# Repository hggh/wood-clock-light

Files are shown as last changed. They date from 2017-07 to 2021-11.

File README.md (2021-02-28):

# wood clock with ESP32

a rainbow wood clock with a custom LED matrix with 95 PL9823-F8 RBG LEDs.

 * ESP32
 * 85x pl9823-f8

### rainbow mode
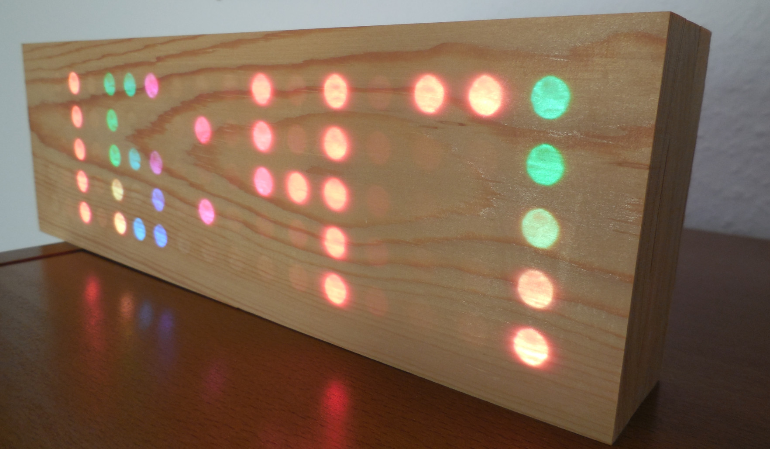
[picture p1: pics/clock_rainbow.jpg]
Wood Clock Wood rainbow

### single color mode controllable via web
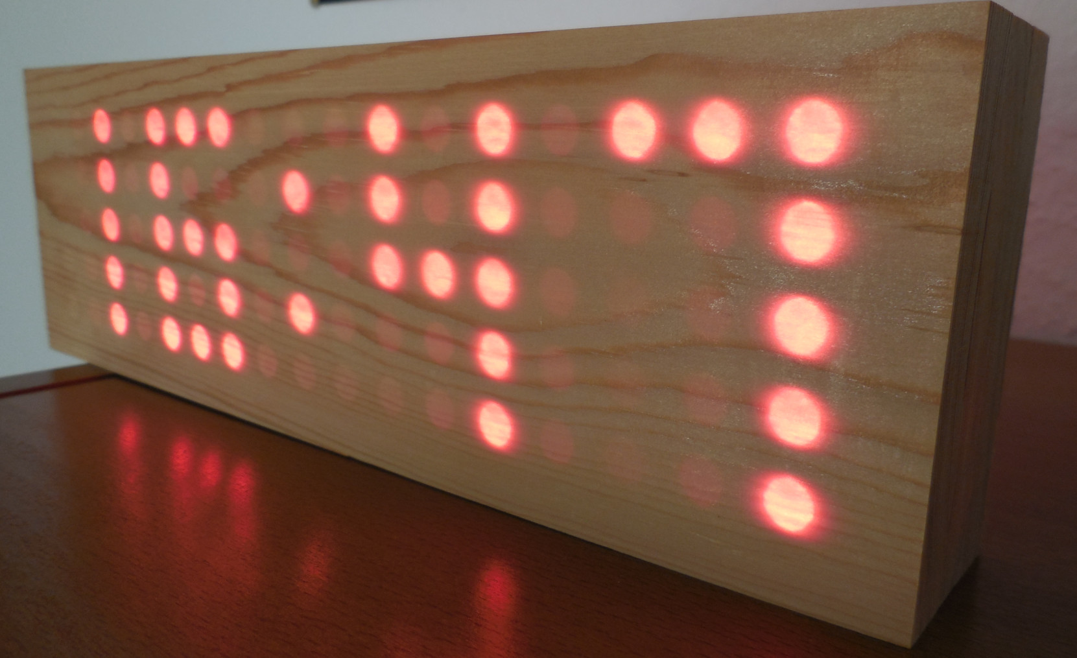
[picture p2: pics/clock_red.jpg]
Wood Clock Wood red

### simple web interface
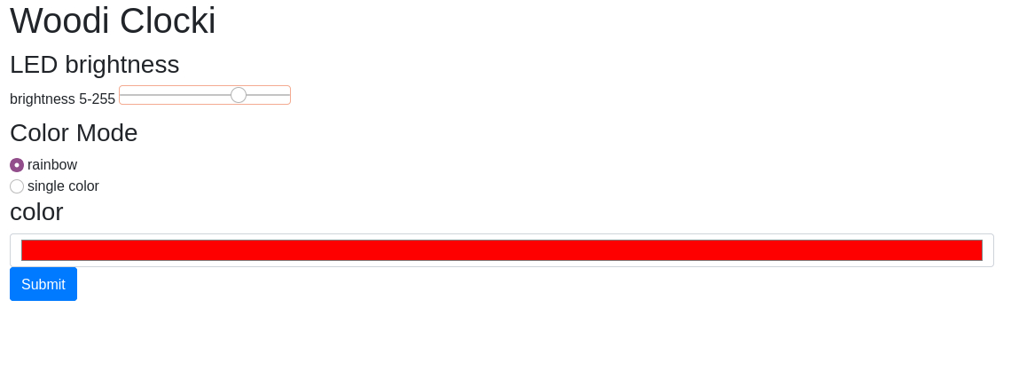
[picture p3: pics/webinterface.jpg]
Wood Clock web interface

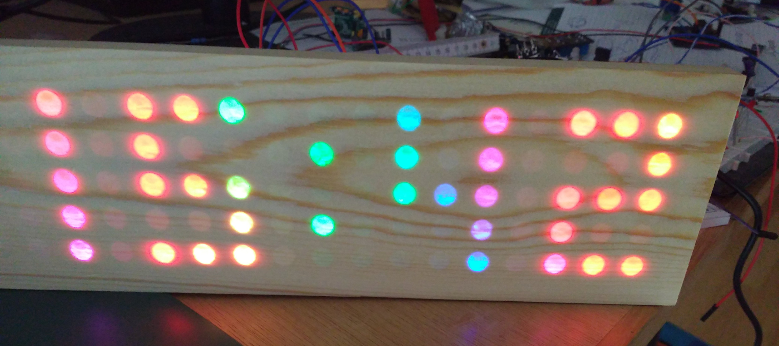
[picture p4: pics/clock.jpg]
Wood Clock


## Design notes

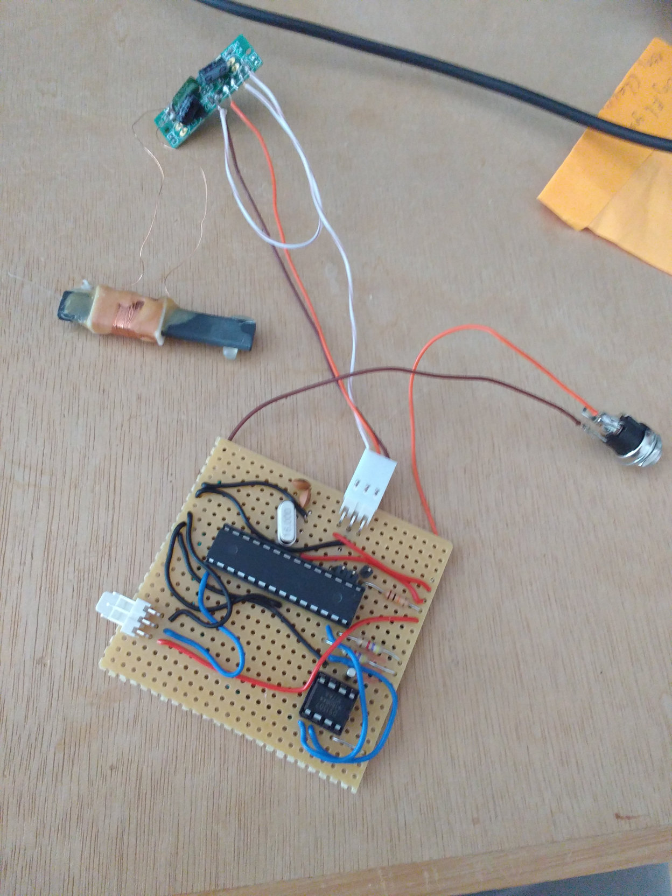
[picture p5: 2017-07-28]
pics/pcb.jpg

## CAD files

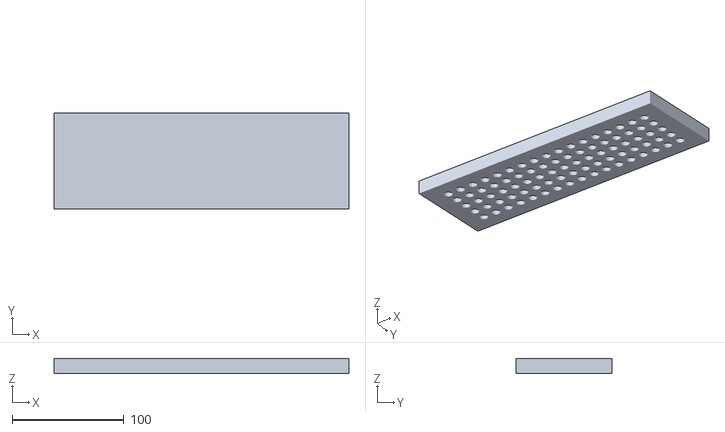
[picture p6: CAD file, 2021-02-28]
svg/wood-clock.stl
264.0 x 86.0 x 13.0

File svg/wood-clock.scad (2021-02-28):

difference() {
  cube(size = [264,86,13]);
  for (e = [ 0 : 4 ]) {
    for (i = [0 : 16]) {
      translate([(20 + (i * 14)),17 + (e *13),0]) {
        cylinder (h = 12.2, r=4, center=false);
      }
    }
  }
}

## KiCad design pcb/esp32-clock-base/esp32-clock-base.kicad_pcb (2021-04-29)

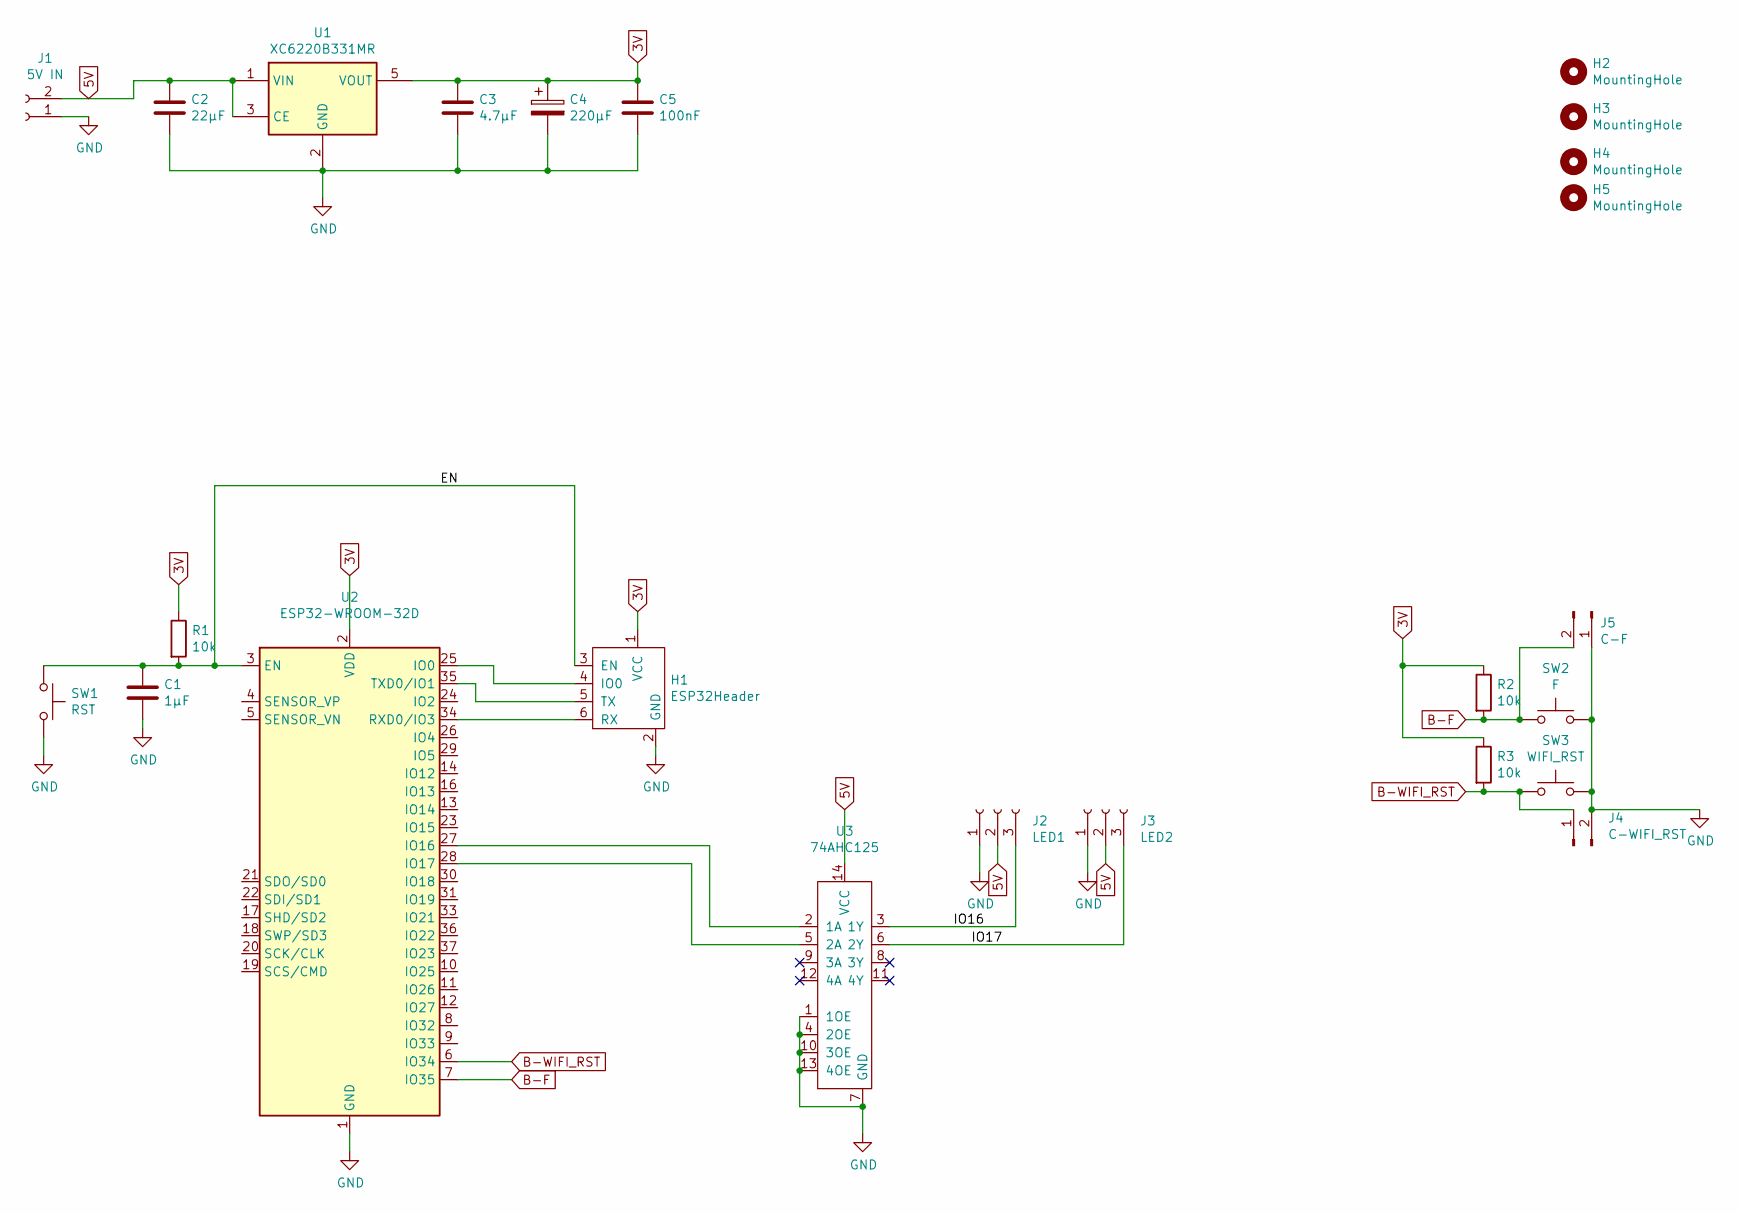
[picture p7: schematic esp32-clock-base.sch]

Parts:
C1: 1µF; C_0805_2012Metric
C2: 22µF; C_0805_2012Metric
C3: 4.7µF; C_0805_2012Metric
C4: 220µF; CP_EIA-7343-31_Kemet-D
C5: 100nF; C_0805_2012Metric
H1: ESP32Header; esp32-prog-header
H2, H3, H4, H5: MountingHole; MountingHole_3.2mm_M3
J1: 5V IN; PinHeader_1x02_P2.54mm_Vertical
J2: LED1; PinHeader_1x03_P2.54mm_Horizontal
J3: LED2; PinHeader_1x03_P2.54mm_Horizontal
J4: C-WIFI_RST; PinHeader_1x02_P2.00mm_Vertical
J5: C-F; PinHeader_1x02_P2.00mm_Vertical
R1, R2, R3: 10k; R_0805_2012Metric
SW1: RST; SMD_Button
SW2: F; SMD_Button
SW3: WIFI_RST; SMD_Button
U1: XC6220B331MR; SOT-23-5
U2: ESP32-WROOM-32D; ESP32-WROOM-32
U3: 74AHC125; SO-14_3.9x8.65mm_P1.27mm

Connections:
3V: C3.1, C4.1, C5.1, H1.1 (VCC), R1.1, R2.1, R3.1, U1.5 (VOUT), U2.2 (VDD)
5V: C2.1, J1.2, J2.2, J3.2, U1.1 (VIN), U1.3 (CE), U3.14 (VCC)
/EN: C1.1, H1.3 (EN), R1.2, SW1.1, U2.3 (EN)
/IO16: J2.3, U3.3 (1Y)
/IO17: J3.3, U3.6 (2Y)
B-F: J5.2, R2.2, SW2.1, U2.7 (IO35)
B-WIFI_RST: J4.1, R3.2, SW3.1, U2.6 (IO34)
GND: C1.2, C2.2, C3.2, C4.2, C5.2, H1.2 (GND), J1.1, J2.1, J3.1, J4.2, J5.1, SW1.2, SW2.2, SW3.2, U1.2 (GND), U2.1 (GND), U2.15 (GND), U2.38 (GND), U2.39 (GND), U3.1 (1OE), U3.4 (2OE), U3.7 (GND), U3.10 (3OE), U3.13 (4OE)
unnamed: H1.4 (IO0), U2.25 (IO0)
unnamed: H1.5 (TX), U2.35 (TXD0/IO1)
unnamed: H1.6 (RX), U2.34 (RXD0/IO3)
unnamed: U2.27 (IO16), U3.2 (1A)
unnamed: U2.28 (IO17), U3.5 (2A)

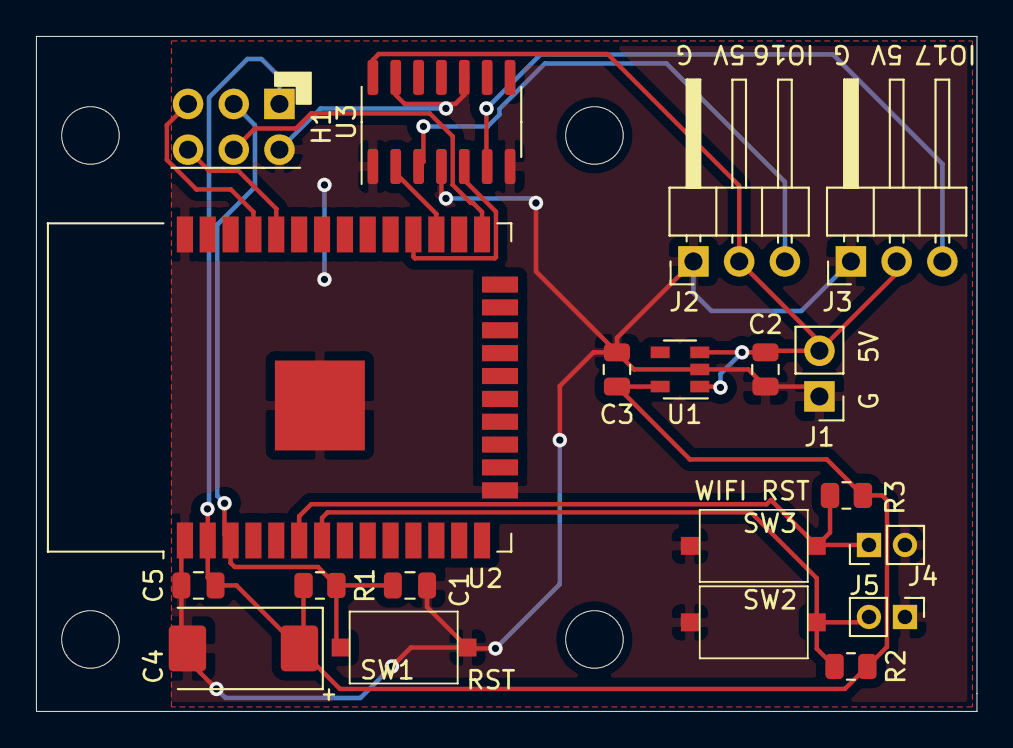
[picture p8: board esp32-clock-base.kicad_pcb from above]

Board: 2 copper layers, 52.2 x 37.5 mm, 24 parts (0 on the bottom side), 13 nets.

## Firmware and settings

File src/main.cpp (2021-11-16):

#include <Arduino.h>
#include "SPIFFS.h"
#include <WiFi.h>
#include <WiFiClient.h>
#include <WiFiClientSecure.h>
#include <time.h>

#include <FastLED.h>
#include <Bounce2.h>
#include <FS.h>
#include <WiFiManager.h>
#include <WebServer.h>
#include <MQTT.h>

#include "display.h"
#include "config.h"

// we have one sacrificial LED with a diode on VCC to push VDD
#define LED_COUNT 85
#define PIN_RGB_LEDS 17
#define PIN_WIFI_RESET 34

#define COLOR_MODE_RAINBOW 1
#define COLOR_MODE_SINGLE_COLOR 2

CRGB leds[LED_COUNT];
CRGB led_color = CRGB::Red;
WiFiManager wm;
WiFiClientSecure net;
MQTTClient mqtt;
Bounce2::Button wifi_cfg_reset = Bounce2::Button();

const long gmt_offset_sec = 3600;
const int  day_light_offset_sec = 3600;

uint8_t time_hour = 255;
uint8_t time_minute = 255;
uint8_t color_mode = COLOR_MODE_RAINBOW;
int led_brightness = 60;
volatile bool auth_token = false;
uint8_t auth_token_number = 0;
bool update_leds = false;
CHSV hsv;

void write_char_to_leds(uint8_t offset, const uint8_t n[15]) {
  for (uint8_t i = 0; i<15; i++) {
    if (n[i] == 1) {
      if (color_mode == COLOR_MODE_RAINBOW) {
        leds[offset + i] = hsv;
        hsv.hue += 10;
      }
      else {
        leds[offset + i] = led_color;
      }
    }
    else {
      leds[offset + i] = CRGB::Black;
    }
  }
}

void clock_display_number(uint8_t offset, uint8_t number, boolean display_zero = false) {
  uint8_t t_first = ((number / 10 ) % 10);
  uint8_t t_second = (number % 10 );

  if (display_zero == true || t_first != 0 ) {
    write_char_to_leds(offset, numbers[t_first]);
  }
  write_char_to_leds(offset + 20, numbers[t_second]);
}

void mqtt_message_received(MQTTClient *client, char topic[], char bytes[], int length) {
  if (String(topic).endsWith("/led_brightness")) {
    update_leds = true;
    led_brightness = String(bytes).toInt();
    FastLED.setBrightness(led_brightness);
  }
  if (String(topic).endsWith("/auth_token")) {
    auth_token = true;
    auth_token_number = String(bytes).toInt();
  }
  if (String(topic).endsWith("/led_color")) {
    update_leds = true;

    String color_string = String(bytes);
    color_string.replace("#", "");
    long color_code_tmp = strtol(color_string.c_str(), NULL, 16);
    led_color = CRGB(color_code_tmp);
  }
  if (String(topic).endsWith("/color_mode")) {
    update_leds = true;

    if (String(bytes).equals("random_color")) {
      color_mode = COLOR_MODE_RAINBOW;
    }
    else {
      color_mode = COLOR_MODE_SINGLE_COLOR;
    }
  }
}

void connect_mqtt() {
  mqtt.connect(HOSTNAME, MQTT_USERNAME, MQTT_PASSWORD);
  mqtt.subscribe(String("/device/" + String(HOSTNAME) + "/led_brightness").c_str(), 1);
  mqtt.subscribe(String("/device/" + String(HOSTNAME) + "/auth_token").c_str(), 1);
  mqtt.subscribe(String("/device/" + String(HOSTNAME) + "/color_mode").c_str(), 1);
  mqtt.subscribe(String("/device/" + String(HOSTNAME) + "/led_color").c_str(), 1);
  mqtt.subscribe(String("/device/" + String(HOSTNAME) + "/show_minute_leds").c_str(), 1);
  mqtt.onMessageAdvanced(mqtt_message_received);
  mqtt.publish(String("/device/" + String(HOSTNAME) + "/boot").c_str(), WiFi.localIP().toString().c_str(), false, 1);
}

void wm_config_mode_callback(WiFiManager *myWiFiManager) {
  Serial.println("Entering WiFI Manager configuration....");

  fill_solid(leds, LED_COUNT, CRGB::DeepPink);
  FastLED.setBrightness(10);
  FastLED.show();
}

void setup() {
  Serial.begin(115200);
  btStop();
  WiFi.mode(WIFI_STA);
  WiFi.setHostname(HOSTNAME);
  Serial.begin(115200);

  hsv.hue = 1;
  hsv.val = 255;
  hsv.sat = 240;

  FastLED.addLeds<PL9823, PIN_RGB_LEDS>(leds, LED_COUNT);
  FastLED.setBrightness(led_brightness);

  if(!SPIFFS.begin(true)){
    Serial.println("error on SPIFFS...");
  }
  wm.setAPCallback(wm_config_mode_callback);
  wm.autoConnect(HOSTNAME, "");

  FastLED.clear(true);

  configTime(gmt_offset_sec, day_light_offset_sec, "0.de.pool.ntp.org", "1.de.pool.ntp.org", "2.de.pool.ntp.org");
  setenv("TZ", "CET-1CEST,M3.5.0,M10.5.0/3", 1);
  tzset();

  wifi_cfg_reset.attach(PIN_WIFI_RESET, INPUT);
  wifi_cfg_reset.interval(25);
  wifi_cfg_reset.setPressedState(LOW);

  net.setCACert(root_ca);
  mqtt.begin(MQTT_SERVER, MQTT_PORT, net);

}

void loop() {
  wifi_cfg_reset.update();
  if (mqtt.connected() == false) {
    connect_mqtt();
  }
  mqtt.loop();

  if (auth_token == true) {
    auth_token = false;
    FastLED.clear();
    clock_display_number(0, auth_token_number, false);
    FastLED.show();

    delay(5000);
    update_leds = true;
  }

  if (wifi_cfg_reset.pressed()) {
    // WiFi reset configuration button was pressed
    wm.resetSettings();
    Serial.println("WiFi reset configuration button was pressed......");
    Serial.flush();
    delay(500);
    ESP.restart();
  }

  struct tm timedate;
  time_t now = time(&now);
  localtime_r(&now, &timedate);

  if (timedate.tm_min != time_minute || timedate.tm_hour != time_hour || update_leds == true) {
    // time has changed, display it on the WS2812b LEDs
    update_leds = false;
    time_minute = timedate.tm_min;
    time_hour = timedate.tm_hour;

    Serial.println("Time has changed...");
    Serial.print("Hour: ");
    Serial.println(time_hour);
    Serial.print("Minute: ");
    Serial.println(time_minute);

    if (time_hour == 0) {
      clock_display_number(0, time_hour, true);
    }
    else {
      clock_display_number(0, time_hour, false);
    }
    write_char_to_leds(35, time_delimiter);
    clock_display_number(50, time_minute, true);

    FastLED.show();
  }
  delay(1);
}

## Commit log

2021-02-28 update to esp32
2021-02-28 add opfer LED; add brightness control to webserver
2021-03-07 update html with current settings
2021-03-15 set correct Europe/Berlin timezone
    [main.cpp]
2021-04-29 add ESP32 base pcb
    [esp32-clock-base.kicad_pcb, esp32-clock-base.sch]
2021-05-06 update to new PCB with 74AHC125
